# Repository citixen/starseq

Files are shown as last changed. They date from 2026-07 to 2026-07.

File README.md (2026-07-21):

# starseq — project overview

This project and all files in it represent the state of the project as it was during EMF Camp 2026, where it ran as an installation (in the baking sun) for 4 days. It largely worked without incident for that time and the concept and implementation are at least a bit proven. However, the project is offered as-is and without any ability to support it further if you decide to try building one for yourself. It all works in my build, but that doesn't mean it will for you. I may have forgotten critical setup components, and I may have done something weird and forgotten to document it. Sorry if I did. I've also not really documented any of the specifics of how I wired it together in my build. It was horrible spaghetti (see pics) and you can definitely do better just using the pin allocations in the code to guide you. Best of luck! Use this as a jumping off point to something bigger and better! I know I will!

---

## what starseq is

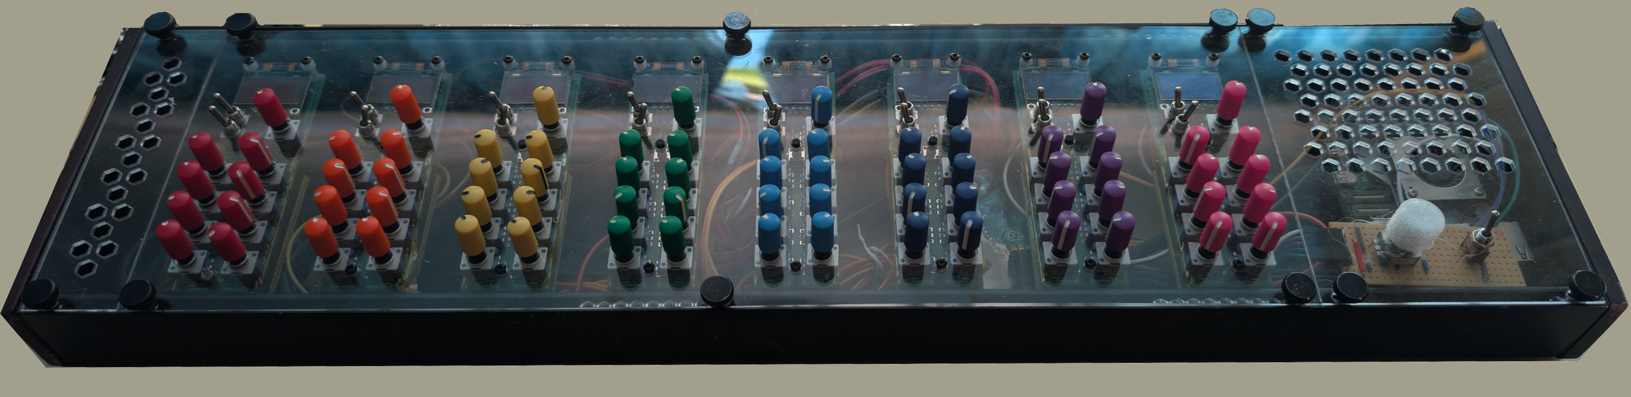
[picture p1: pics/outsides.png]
Image of the control interface for an 8-track sequencer, with a large number of coloured potentiometers and a perspex panel behind which can be seen a raspberry pi


**starseq** is an 8-track MIDI step sequencer whose musical content is generated from the real-time positions of naked-eye-visible stars in the sky above the instrument's physical location. Each of the 8 tracks claims a wedge ("slice") of the compass — a band of azimuth and a brightness threshold — and turns whichever stars currently sit inside that wedge into a step sequence: azimuth decides *when* (which step) a note falls, altitude decides *what pitch*, and brightness/colour decide *how loud* and *how long*. Because the sky moves, the sequences drift and evolve on their own, in real astronomical time or sped up/slowed/reversed via a simulated clock. Planets and constellation lines are drawn for visual context only currently — but the data is there for future uses.

The instrument is physically and electronically a three-tier system:

```
┌──────────────────────┐      ┌──────────────────────┐     ┌─────────────────────┐
│ 8 × Instrument       │      │ Controller Interface │     │ Sequencer           │
│ Controllers          │────▶│  (aggregator)        │────▶│ (Raspberry Pi 5)    │
│ (one per track)      │ UART │ RP2040 Pico          │ UART│ Sky engine, MIDI,   │
│ 9 pots + 2 switches  │      │                      │     │ display, output     │
│ + button + OLED      │      │                      │     │                     │
└──────────────────────┘      └──────────────────────┘     └─────────────────────┘
     ESP32-S3 DevKit             8-port aggregator            pygame + skyfield
     per track                  → single uplink               + MIDI + GPIO
```

A performer turns physical pots on 8 identical hand controllers; those settings flow up through an aggregating interface board to a Raspberry Pi, which combines them with live sky data to produce and play an 8-track MIDI sequence, rendered simultaneously as a star-dome visualisation.

The instrument is housed in a standard cheap 104hp eurorack case, with some cheap bulkhead pass-thrus to get USB and HDMI from the Pi outside the case, and to get power in.

---

## tier 1 — instrument controller (one per track, ×8)

**Hardware:** ESP32-S3 DevKit C-1 (cheap - and has 2 x 12-bit SAR ADCs). Per unit: 9 potentiometers, 2 SPDT switches (Mute/Stop; Mono/Poly), 1 momentary push-button (play direction), a 128×64 SSD1306 2 colour (yellow/blue) OLED over I2C (mounted inverted, yellow  strip at the bottom), and a UART link out to the Controller Interface. The PCB files are included for the version used at EMF 26. These were made quickly and down to a price. Better board layouts and control configurations can be achieved!

**Role:** turn physical control positions into a per-track parameter packet and keep the OLED showing current state.

In the published firmware, all 9 pots are live simultaneously on a single page (an earlier multi-page design was collapsed to one page for simplicity). Each pot drives one parameter directly: length, base note, note range, slice centre, step divider, slice width, play mode, slice brightness, and duration max (which rescales live across `1…current length`). The two switches and the button cover mute/stop, mono/poly, and play-direction toggle. Parameters that are sent from the controller but which no longer have a dedicated pot in this  revision — velocity lo/hi, duration lo, parameter mode, MIDI channel — are  held at fixed firmware defaults but are still transmitted in full on every  packet, because **the wire format was deliberately left unchanged** from an  earlier, fuller-featured revision. This means the interface and sequencer  require no changes to accept this simplified controller, and a future firmware  revision could re-expose those parameters on interface pages without touching  downstream code.

The controller debounces inputs, applies deadbanding to pot readings to try  to avoid flooding the serial link with jitter, and transmits change-driven updates plus a periodic heartbeat. It persists its working state to the ESP32's flash-backed NVS (a packed, versioned, CRC-checked 22-byte struct), so a power cycle resumes the previous session instead of resetting to defaults — with **pick-up logic** at boot only: a restored pot value is shown with a directional arrow on the OLED until the performer physically turns that pot through the stored value, at which point it goes live.

---

## tier 2 — controller interface (aggregator)

**Hardware:** a single Raspberry Pi Pico (RP2040), with 8 independent PIO-UART port pairs (one RX/TX pair per controller) plus one hardware UART uplink to the Raspberry Pi. All built onto a small vero board, along with power distribution for the controllers. Takes in a single USB-C connection for 5V.

**Role:** a hardware-agnostic multiplexer. It runs 8 concurrent per-port receivers, validates and decodes each controller's packet (frame boundaries, protocol version, CRC, field ranges), maintains a live state table (one record per controller, with sequence number, last-RX timestamp, and a waiting/online/stale/offline status derived from timeout), and republishes that aggregated state upstream to the Pi as a single serial stream. A single-port fault never blocks the other 7 ports.

Two upstream message shapes exist: periodic **full snapshots** (all 8 controller records in one packet, sent roughly every 400 ms) and **delta packets** (a single controller's record, sent immediately whenever a field changes beyond a small deadband). This keeps the uplink responsive to live pot movement without needing to stream continuously.

---

## tier 3 — sequencer (Raspberry Pi 5)

**Hardware:** a Raspberry Pi 5, with a serial connection to the interface board, a 20 pulse rotary encoder and an SPDT connected to GPIO pins. Outputs HDMI, and has USB connections - all passed through the case.

**Role:** the brain of the instrument. Runs headlessly, receives the  aggregated controller state over serial, computes the live sky, turns  sky + per-track parameters into MIDI, and renders everything to an HDMI/DSI display via pygame.

### architecture

The application is a set of daemon background threads (Serial RX, Input Handler, Sky Engine, Sequence Builder, Sequencer Engine, MIDI Clock Input, GPS Receiver) plus one blocking main-thread loop for the pygame display — pygame's video backend must own the main thread on Linux/the Pi. Shared state moves through thread-safe primitives only: per-track locks, bounded queues, and a lock-free double-buffered (plus one "pending") sequence store per track. The sequencer engine requests real-time (`SCHED_FIFO`) scheduling and is never allowed to block on sky computation, serial I/O, GPS parsing, or rendering.

### midi generation

1. **Sky Engine** recomputes, on a fixed ~250 ms interval, the alt/az of    every star in the Yale Bright Star Catalogue (via Skyfield/DE421) and of     7 planets, using a **simulated clock** that can run at real speed, be     frozen, fast-forwarded, or reversed (a discrete multiplier ladder from     ‑64× to 64×), or jumped to an explicit date via a preset events picker     or manual date fields. Only stars above the horizon and brighter than     magnitude 6.5 (naked-eye) survive into the published snapshot; planets     are published on a separate, sequencing-blind channel.
2. **Sequence Builder** takes each track's slice (`slice_centre` ±    `slice_width/2`, wrap-around handled mod 360) and `slice_brightness`    (mapped to a magnitude cutoff), filters the star snapshot down to that    track's candidate stars, buckets them into steps by azimuth, assigns each    a MIDI note from altitude (mapped onto the valid in-scale notes within    `base_note … base_note + note_range`), and picks which candidate(s) in a    step actually sound according to the track's **play mode** (random,    highest, lowest, middle, first, last, brightest, dimmest) and mono/poly    mode. Velocity comes from magnitude and duration from B‑V colour index    (or from static/per-loop-randomised values, depending on `param_mode`).    Loop-randomised tracks stage their next sequence in a third "pending"    buffer so a re-roll never disturbs a note already playing mid-loop; the    swap happens only at that track's own loop boundary.
3. **Sequencer Engine** is the real-time clock: internal PPQN-24 tick    generation or external MIDI clock, per-track step/tick accumulators so    tracks can run at independent step-dividers while staying phase-locked,    forward/reverse play direction, note-on/note-off scheduling, and MIDI    output. It also drives the flash events consumed by the display so that    firing notes visibly pulse on the star dome and sequencer grid in the    same colour as the track that's playing them.
4. **MIDI channel routing** is decoupled from whatever channel a controller    itself reports: a transport-bar **CH MODE** setting chooses between the    controller-launch default, sequential per-track channels, all-tracks-on-    one-channel, or trusting the controller's own reported channel.

### display

A pygame UI running at 30 fps shows a polar-projected star dome (stars, planet hexagon markers, constellation lines), an 8-row sequencer grid, and an always-visible transport bar (no modal menu — a single focus pointer moves around a flat ring of stops for location, view/brightness toggles, tempo, clock source, key/scale, polyphony limit, MIDI device, channel mode, and simulated time). Layout adapts automatically to portrait, landscape, or extreme-aspect screens, and three independent brightness toggles plus a 10-mode **VIEW** setting control how much of the sky, wedges, and note flashes are visible without ever touching what's actually being sequenced.

### inputs

A rotary encoder + SPDT play/stop switch (GPIO on the Pi) provide local transport control, with a keyboard fallback for headless/dev use. Location can come from config defaults, manual entry, a USB NMEA GPS receiver, or a built-in list of preset cities — switchable live, without a restart.

---

## end-to-end data flow

```
Pot/switch/button position (Instrument Controller)
   → smoothed, deadbanded, mapped to parameter range
   → packed into a 21-byte controller record, COBS-framed, CRC-8
   → UART to Controller Interface

Controller Interface
   → validated per-port, staged into a per-controller state table
   → status (waiting/online/stale/offline) derived from packet recency
   → re-aggregated into full (8-record) or delta (1-record) packets
   → COBS-framed, CRC-8, UART uplink to Raspberry Pi

Raspberry Pi — Serial RX thread
   → CRC-checked, decoded, written directly into that track's TrackState
     under its lock; sequence_dirty = True

Sky Engine (independent of the above)
   → simulated time → star & planet alt/az → filtered snapshot published

Sequence Builder
   → combines the track's parameters with the star snapshot
   → produces a step sequence (notes, velocities, durations)

Sequencer Engine
   → ticks, advances steps, fires MIDI Note On/Off, schedules flash events

MIDI Output + Display
   → notes/clock out over MIDI; star dome & grid rendered in sync
```

A single 21-byte controller record schema is shared verbatim across all three tiers — the Instrument Controller populates it, the Controller Interface forwards it unmodified, and the Sequencer is the only tier that interprets it semantically (resolving the step-divider index to an actual ratio, applying channel-mode overrides, etc.).

---

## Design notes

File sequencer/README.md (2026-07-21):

# starseq

An 8-track MIDI step sequencer whose musical sequences are derived from the real-time positions of naked-eye-visible stars in the sky above the instrument's location. Runs headlessly on a Raspberry Pi 5 with a pygame UI on an attached HDMI or DSI display.

---

## Hardware requirements

| Component | Notes |
|---|---|
| Raspberry Pi 5 | Tested target; Pi 4 may work with reduced sky recalculation rate |
| HDMI or DSI display | Any resolution ≥ 800 × 480 |
| MIDI interface | USB class-compliant or GPIO UART MIDI out |
| Controller interface | Connected to UART0 (BCM 14/15) at 57600 8N1 |
| Rotary encoder | CLK → BCM 17, DT → BCM 18, SW → BCM 27 (pull-ups applied in software) |
| SPDT play/stop switch | → BCM 16 (pull-up applied in software) |

All hardware inputs are optional at runtime — see [Command-line arguments](#command-line-arguments).

---

## OS requirements

**Raspberry Pi OS Bookworm Lite** (headless, no desktop environment). A desktop environment is not required or expected. The display is driven directly via KMS/DRM.

---

## Software installation

### 1. Clone the repo to the Pi

```bash
git clone <repo-url> ~/starseq
cd ~/starseq
```

Or copy files over SSH:

```bash
scp -r ./starseq pi@<pi-address>:~/starseq
```

### 2. Install system SDL2 development packages

pygame must be compiled against the system SDL2 to gain KMS/DRM display support. Install the development headers first:

```bash
sudo apt update
sudo apt install --no-install-recommends \
    libsdl2-dev libsdl2-image-dev libsdl2-ttf-dev \
    libsdl2-mixer-dev python3-dev
```

### 3. Create and activate a Python virtual environment

```bash
cd ~/starseq
python3 -m venv .venv
source .venv/bin/activate
```

### 4. Install Python dependencies

```bash
pip install -r requirements.txt
```

### 5. Install pygame from source

The pre-built pygame wheel from PyPI bundles its own SDL2 which does not include the KMS/DRM driver required for Bookworm Lite. Compiling from source links against the system SDL2 instead:

```bash
pip install --force-reinstall --no-binary pygame pygame
```

This takes several minutes on the Pi. Verify the correct SDL version afterwards:

```bash
python -c "import pygame; print(pygame.get_sdl_version())"
# Should print (2, 26, x) — the system SDL2 version, not (2, 28, x)
```

### 6. Add the user to the display device groups

KMS/DRM access requires membership of the `video` and `render` groups:

```bash
sudo usermod -a -G video,render $USER
```

Log out and back in for the group change to take effect.

### 7. Verify the data files are present

```
data/de421.bsp      ← JPL ephemeris (~17 MB, included)
data/bsc5.json      ← Yale Bright Star Catalog (included)
```

If `de421.bsp` is missing, skyfield can download it on first run (requires internet access). Place the downloaded file in the `data/` directory.

---

## Configuration

All tuneable constants live in [`config.py`](config.py). Edit them directly before deploying.

### Geographic location

```python
LOCATION_LAT  = 51.75    # decimal degrees (positive = North)
LOCATION_LON  = -0.22    # decimal degrees (positive = East)
LOCATION_ELEV = 80       # metres above sea level
```

### Serial port

By default the serial RX thread opens `/dev/ttyAMA0` (UART0 on the Pi). Override at runtime:

```bash
SERIAL_PORT=/dev/ttyS0 python main.py
```

Or change the default in `config.py`:

```python
SERIAL_PORT = "/dev/ttyAMA0"
```

### Display options

```python
SHOW_OUT_OF_SCOPE_STARS = True    # False hides stars not in any slice
SHOW_MIDI_NOTE_LABELS   = False   # True shows sounding note names in the grid
TARGET_FPS              = 30
```

### Sequencer defaults

```python
MAX_POLY_NOTES         = 5        # maximum simultaneous notes per track in poly mode
PPQN                   = 24       # MIDI clock resolution (standard)
SKY_RECALC_INTERVAL_MS = 250      # minimum ms between sky recomputations
```

---

## Enabling UART0 on the Pi

The Pi's primary UART must be freed from the Bluetooth controller and enabled for general use.

Add to `/boot/firmware/config.txt`:

```
dtoverlay=disable-bt
enable_uart=1
```

Disable the serial console:

```bash
sudo raspi-config
# → Interface Options → Serial Port
# "Would you like a login shell accessible over serial?" → No
# "Would you like the serial port hardware to be enabled?" → Yes
```

Reboot.

---

## Running

### Command-line arguments

```
python main.py [--no-gpio] [--no-serial] [--resolution WxH]
```

| Argument | Effect |
|---|---|
| `--no-gpio` | Skip the GPIO input handler. Use keyboard shortcuts instead (see [Controls](#controls)). |
| `--no-serial` | Skip the serial RX thread. All 8 tracks are initialised with built-in defaults so the sequencer produces sound without a controller attached. |
| `--resolution WxH` | Force a specific window size, e.g. `800x480` or `1920x1080`. Useful for testing layouts at different screen sizes. |

These flags are independent and can be combined:

```bash
# Full hardware
python main.py

# Pi with display + MIDI, no controller attached yet
python main.py --no-serial

# Development on a desktop machine (no GPIO, no serial)
python main.py --no-gpio --no-serial
```

### SDL video driver (automatic)

The display renderer auto-detects the SDL video driver at startup. No environment variables need to be set manually:

| Environment | Driver selected |
|---|---|
| Wayland session (`WAYLAND_DISPLAY` set) | `wayland` |
| X11 session (`DISPLAY` set) | `x11` |
| Bookworm Lite / no display server | `kmsdrm` (requires `video`/`render` group membership) |

The selected driver is logged at startup. Override by setting `SDL_VIDEODRIVER` before launching if needed.

### Foreground (development / testing)

```bash
cd ~/starseq
source .venv/bin/activate
python main.py --no-gpio --no-serial
```

### Autostart on boot (systemd)

Create `/etc/systemd/system/starseq.service`:

```ini
[Unit]
Description=starseq
After=network.target sound.target

[Service]
User=<user>
WorkingDirectory=/home/<user>/starseq
ExecStart=/home/<user>/starseq/.venv/bin/python main.py
Restart=on-failure
RestartSec=5
SupplementaryGroups=video render audio
StandardOutput=journal
StandardError=journal

[Install]
WantedBy=multi-user.target
```

No `DISPLAY` or `SDL_VIDEODRIVER` environment variables are needed — the application detects the correct driver automatically. If the Pi boots to a desktop session, set `Environment=SDL_VIDEODRIVER=wayland` (or `x11`) explicitly to skip the auto-detection.

Enable and start:

```bash
sudo systemctl daemon-reload
sudo systemctl enable starseq
sudo systemctl start starseq
```

View logs:

```bash
journalctl -u starseq -f
```

---

## Real-time scheduling (recommended)

The sequencer engine thread requests `SCHED_FIFO` priority automatically. Grant the permission without running as root:

```bash
sudo nano /etc/security/limits.d/starseq.conf
```

```
<user>  -  rtprio  99
<user>  -  memlock  unlimited
```

Log out and back in (or reboot) for this to take effect.

---

## Controls

### Physical (Raspberry Pi hardware)

| Control | Action |
|---|---|
| SPDT switch | Toggle global play / stop |
| Rotary encoder — turn | Adjust the focused parameter (BPM by default) |
| Encoder button — short press | Advance focus to the next parameter in the transport bar |
| Encoder button — hold ≥ 2 s | Reset simulated sky clock to current UTC (multiplier unchanged) |

### Keyboard (always available in the pygame window)

| Key | Action |
|---|---|
| `P` | Toggle play / stop |
| `R` | Reset simulated sky clock to current UTC |
| `Space` / `Enter` | Advance focus to the next parameter in the transport bar |
| `↑` / `↓` | Navigate parameters without changing value |
| `→` / `+` / `=` | Increase focused parameter value |
| `←` / `-` | Decrease focused parameter value |
| `Escape` | Quit |

### Parameter bar

The transport bar across the top of the window is the parameter menu — it is always visible. All global parameters are shown as labelled columns; the focused column is highlighted.

| Parameter | Range / options |
|---|---|
| Location menu | menu for location settings |
| Constalations | switch on/off |
| Planets | switch on/off |
| BPM | 20.0 – 300.0 (step 1) |
| Clock Source | internal / external |
| Key | C, C#, D … B |
| Scale | Major, Minor, Dorian, Phrygian, Lydian, Mixolydian, Locrian, Whole Tone, Pentatonic Maj, Pentatonic Min, Chromatic |
| Max Poly | 1 – 8 notes per step |
| MIDI Device | cycles through connected output ports |
| MIDI Channel mode | default, sequential, all 1 channel, self-report |
| Time Multiplier | x1, x2, x4, x8 … x64, FROZEN, and negative mirror values |
| Clock menu | menu for clock settings |
| Layout | switch between showing tracks, dimming tracks, and hiding tracks |

Changing **Key**, **Scale**, or **Max Poly** immediately triggers a sequence rebuild on all tracks. Changing **MIDI Device** reopens the MIDI output port.

---

## Display layout

```
┌─────────────────────────────────────────────────────────────────────────────────────────────────────────────────────────────┐
│ LOC | CONST | PLNT | VIEW | PULSE | 120.0 BPM |  INT | C |  MAJ | POLY 5 | USB MIDI | MIDI CH MODE | x1 | CLK | LAYOUT | ▶ │  ← transport bar
├──────────────────────────────────────────────────────────────┬──────────────────────────────────────────────────────────────┤
│                                                              │  track 1 ████████████████░░░░░░░░░░░░░░░░  ▶                │
│              star dome                                       │  track 2 ████████████░░░░░░░░░░░░░░░░░░░░  ▶                │
│             (polar plot,                                     │  track 3 ░░░░░░░░░░░░░░░░░░░░░░░░░░░░░░░░  ■                 │
│               N at top)                                      │  ...                                                         │
│                                                              │  track 8 ████████████████████████████████  ▶                │
└──────────────────────────────────────────────────────────────┴──────────────────────────────────────────────────────────────┘
```

- **Star dome**: circular polar projection; centre = zenith, edge = horizon, north at top. Track slice wedges are outlined in their track colour. Stars are coloured by which track's slice they fall in. Stars pulse briefly when a note fires from them.
- **Sequencer grid**: 8 rows (one per track); each row divided into `length` step cells. The active step is highlighted. Small dots within each cell show the notes available at that step, positioned vertically by MIDI pitch. Stale or offline controller rows are hatched.
- **Transport bar**: always-on strip showing Location menu, constellaion and planet switches, BPM, clock source, key, scale, max poly, MIDI device, time multiplier, clock controls, and play/stop icon.

---

## Simulated time multiplier

The sky engine runs on a simulated clock that can be accelerated, frozen, or reversed relative to wall-clock time. Set it via the **Time Multiplier** entry in the parameter menu.

| Multiplier | Effect |
|---|---|
| `x1` | Real time — sky matches actual UTC |
| `> x1` | Fast-forward — stars sweep faster |
| `FROZEN` | Sky locked at current simulated moment |
| Negative | Stars move backward |

Changing the multiplier only changes the rate of advance. Not the time. The **long-hold gesture** (≥ 2 s on the encoder button, or `R` on keyboard) snaps the simulated clock back to current UTC (as best as the Pi knows. With no NTP it resets to whatever the last "known" time was) without altering the multiplier.

If the simulated time drifts outside the bounds of the ephemeris data (approximately 1900–2050 for DE421), the clock is automatically reset to current UTC.

---

## Development and testing on other systems

```bash
# Windows (PowerShell)
.venv\Scripts\activate
python main.py --no-gpio --no-serial --resolution 1280x720

# macOS / Linux
source .venv/bin/activate
python main.py --no-gpio --no-serial --resolution 1280x720
```

- `--no-gpio` suppresses the `gpiozero/lgpio not available` warning and skips the idle input handler thread.
- `--no-serial` prevents errors from a missing serial port and starts all tracks in playable mono mode immediately.
- `--resolution` is recommended on desktop to get a windowed (non-fullscreen) display.
- MIDI output works via any rtmidi backend (Windows MIDI Mapper, CoreMIDI, ALSA).

---

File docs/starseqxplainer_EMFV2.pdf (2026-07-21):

# starseq - music from the stars

An 8-track sequencer that reads its notes from the sky.

The sky is the score

Each of the 8 tracks watches a slice of sky - an arc of azimuth with a centre and a width. Only stars inside a track's slice, and bright enough to pass its threshold, can sound on that track. As the sky turns, the sequence rebuilds.

A slice splits into as many step-wedges as the track's length. When several stars share a step, play mode picks which sound (random, highest/lowest, brightest/dimmest…). Mono keeps one; poly keeps many.

Anywhere, any when, any speed

The device knows where it is using GPS, and uses that to calculate the visible stars. You can manually set this to any lat/lon - or pick from a list of presets - and automatically travel to that location!

The sky runs on a simulated clock. The time multiplier can speed it up, freeze it, or reverse it, without ever jumping. A long-press on the encoder snaps it back to the real moment. Or you can set the time to a significant event and experience what the stars sounded like then.

Instant space and time travel at the turn of a dial!

The skydome

Represents a polar plot of the sky: zenith at centre, horizon at the edge, north at top. Stars pulse on a note-on. Planets are hexagon markers - and are visual only, not sequenced.
View modes sets how brightly this is all drawn.

Star properties → musical parameters

STAR | TRACK/STEP/NOTE
Altitude height above horizon | Pitch, within scale & note range
Azimuth angle from slice center | Step position

B−V colour
index
blue → red

Note duration

Magnitude
apparent
brightness

Velocity, and the slice
brightness gate

Musical - or not

The user can apply tempo, scale and key constraints, with which to constrain the generation of musical notes and steps. Or chromatic mode can be applied for some chaos!

Tempo can be set externally, or can be sent out from the sequencer to other midi devices.

# starseq - controller

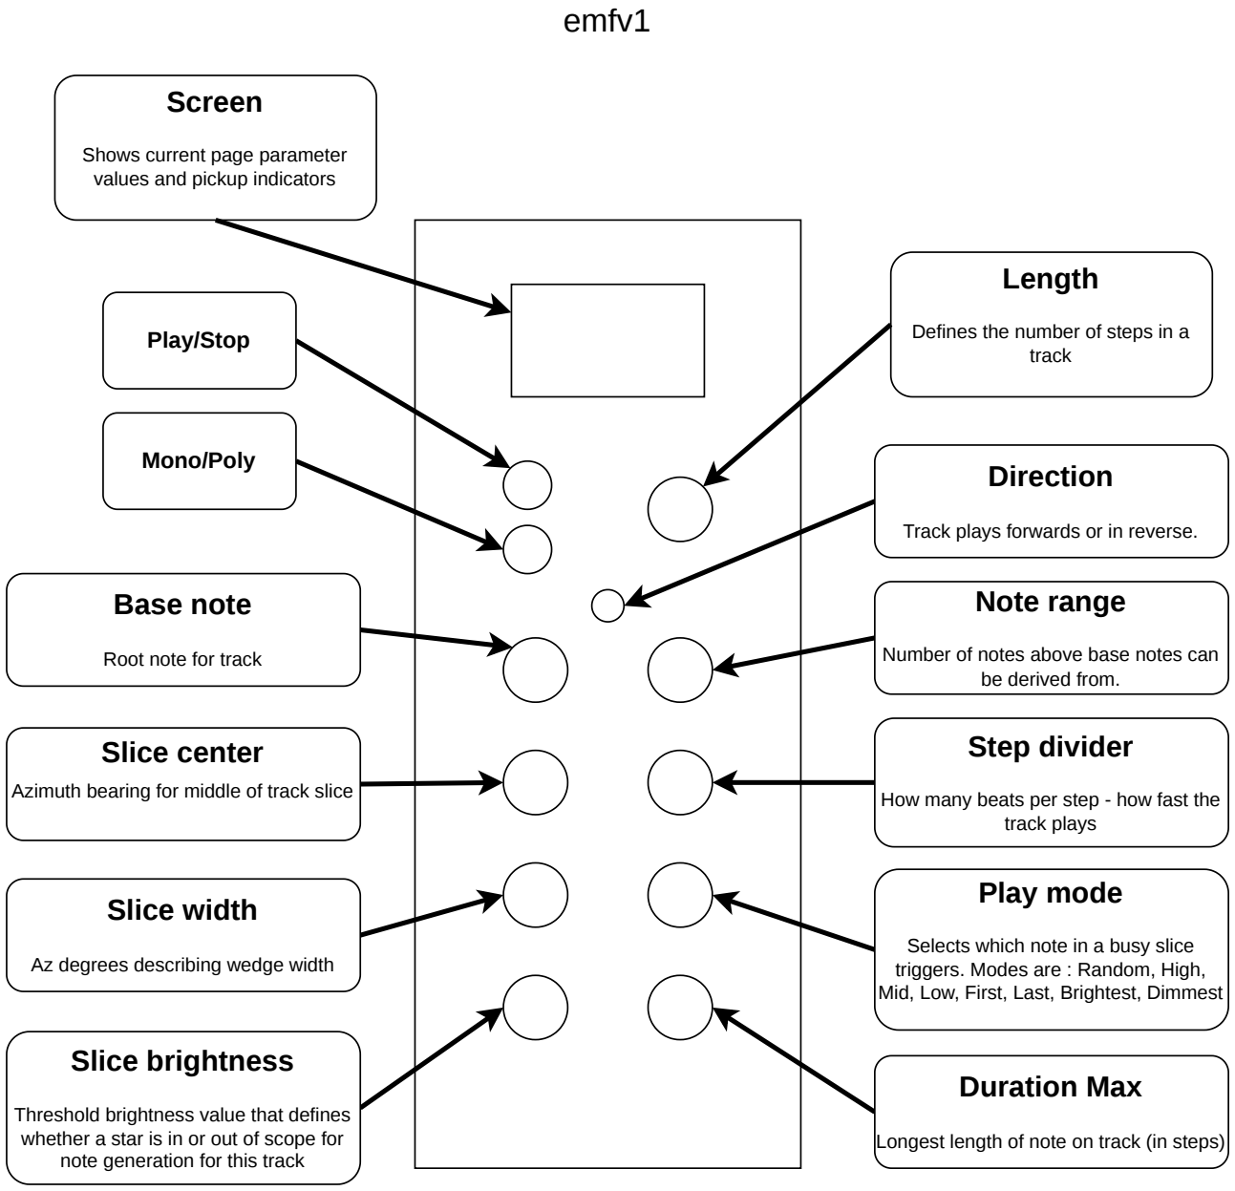
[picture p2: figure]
Screen; Shows current page parameter values and pickup indicators; Length; Defines the number of steps in a track; Play/Stop; Mono/Poly; emfv1; Duration Max; Direction; Track plays forwards or in reverse.; Base note; Root note for track; Play mode; Selects which note in a busy slice triggers. Modes are : Random, High,; Step divider; How many beats per step - how fast the track plays; Note range; Number of notes above base notes can be derived from.; Slice center; Slice width; Az degrees describing wedge width; Slice brightness; Threshold brightness value that defines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

Longest length of note on track (in steps)

Mid, Low, First, Last, Brightest, Dimmest

Azimuth bearing for middle of track slice

whether a star is in or out of scope for

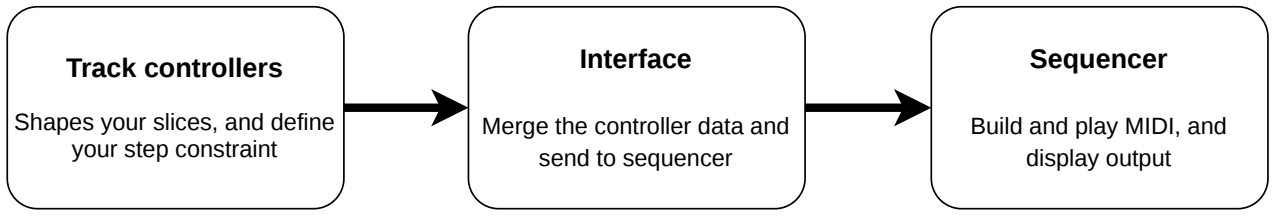
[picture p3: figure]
Track controllers; Shapes your slices, and define your step constraint; Interface; Merge the controller data and send to sequencer; Sequencer; Build and play MIDI, and display output

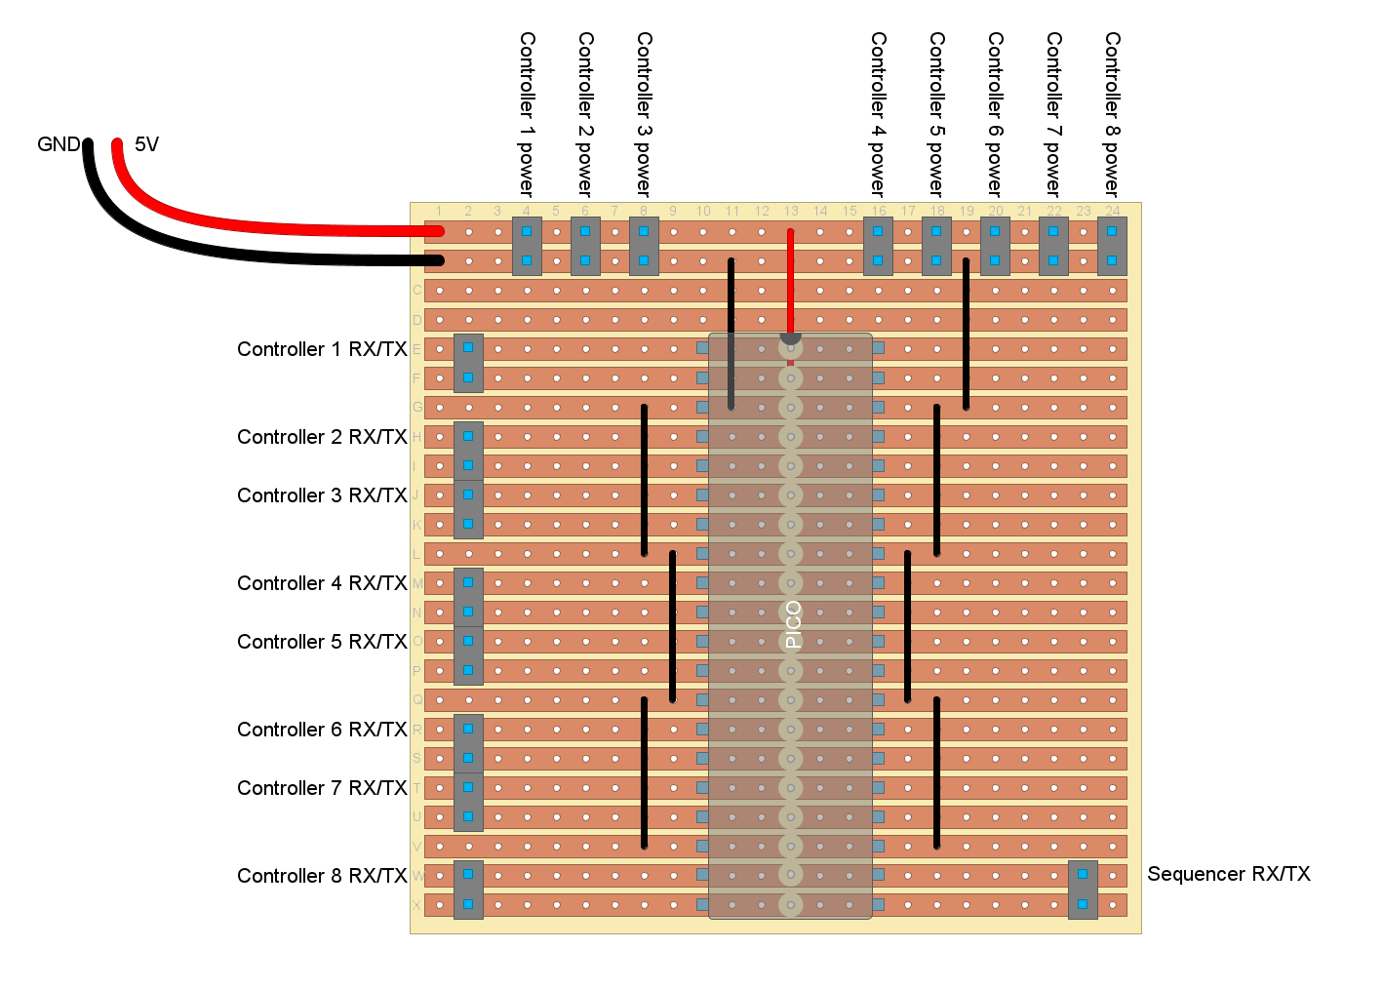
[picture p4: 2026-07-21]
hardware/interface/interface vero layout.png

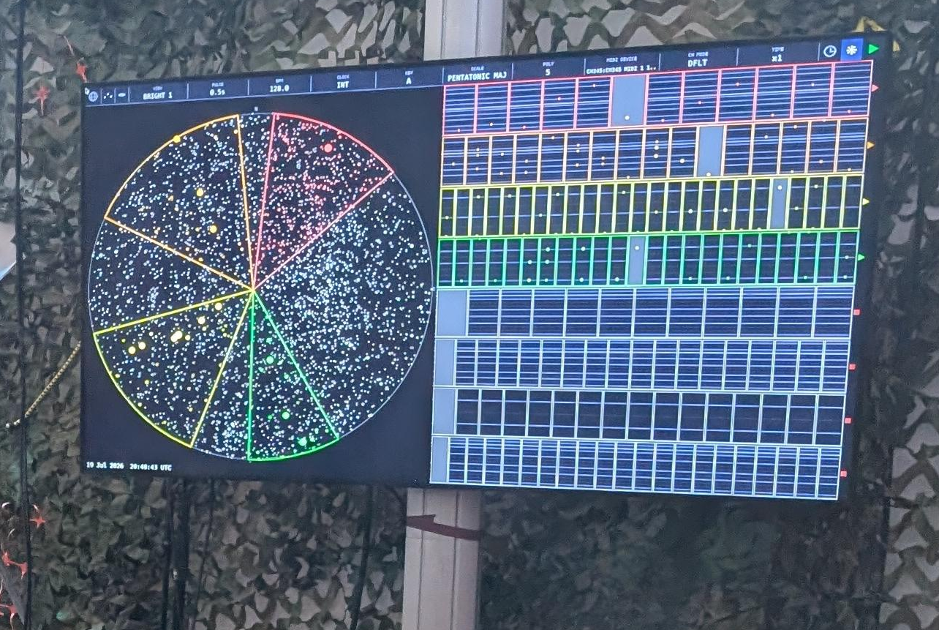
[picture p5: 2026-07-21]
pics/interfaceinaction.png

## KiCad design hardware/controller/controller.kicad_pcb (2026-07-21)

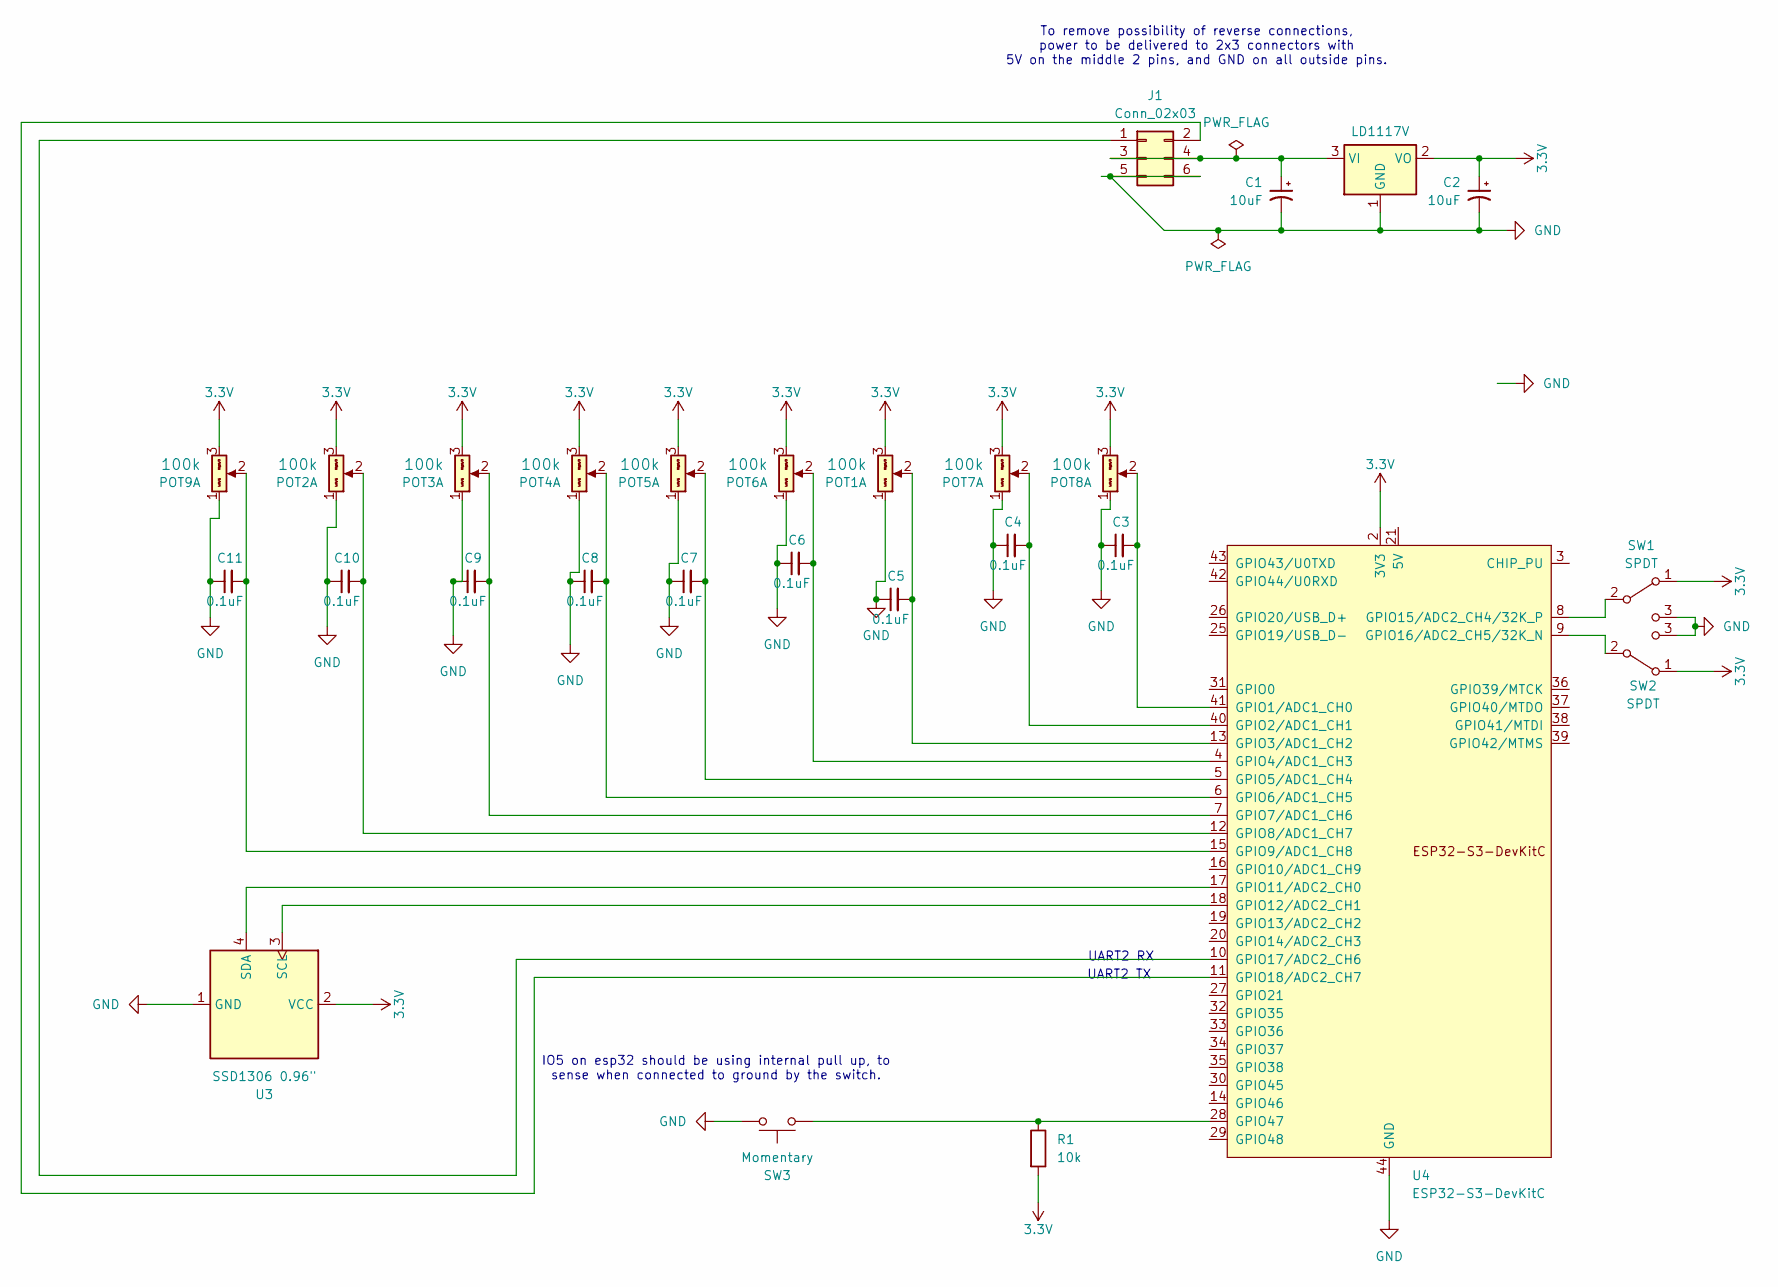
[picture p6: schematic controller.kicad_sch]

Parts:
C1, C2: 10uF; CP_Radial_D5.0mm_P2.50mm; Part Number EEE-FN1A100R; JLCPCB ID C176661
C3, C4, C5, C6, C7, C8, C9, C10, C11: 0.1uF; C_0805_2012Metric_Pad1.18x1.45mm_HandSolder; Voltage 25V; Tolerance 20%
J1: Conn_02x03; PinHeader_2x03_P2.54mm_Vertical
POT1, POT2, POT3, POT4, POT5, POT6, POT7, POT8, POT9: 9mm_NoDet_100k_Knurled_Lined; Pot_9mm_regularstylewiderleg; Part Number RV16AF-4A-15FW-B100K-3
R1: R_Generic; R_Axial_DIN0207_L6.3mm_D2.5mm_P10.16mm_Horizontal
SW1, SW2: SPDT; Switch_Toggle_SPDT_SubMini
SW3: Momentary; SW_PUSH_6mm
U2: LD1117V; TO-220-3_Horizontal_TabDown
U3: SSD1306 0.96"; 128x64OLED 0.96
U4: ESP32-S3-DevKitC; ESP32-S3-DevKitC-WIDER

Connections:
3.3V: C2.1, POT1.3 (Right), POT2.3 (Right), POT3.3 (Right), POT4.3 (Right), POT5.3 (Right), POT6.3 (Right), POT7.3 (Right), POT8.3 (Right), POT9.3 (Right), R1.2, SW1.1 (A), SW2.1 (A), U2.2 (VO), U3.2 (VCC), U4.1 (3V3), U4.2 (3V3)
GND: C1.2, C2.2, C3.1, C4.1, C5.1, C6.1, C7.1, C8.1, C9.1, C10.1, C11.1, J1.5, J1.6, POT1.1 (Left), POT2.1 (Left), POT3.1 (Left), POT4.1 (Left), POT5.1 (Left), POT6.1 (Left), POT7.1 (Left), POT8.1 (Left), POT9.1 (Left), SW1.3 (C), SW2.3 (C), SW3.2, U2.1 (GND), U3.1 (GND), U4.22 (GND), U4.23 (GND), U4.24 (GND), U4.44 (GND)
unnamed: C5.2, POT1.2 (Center), U4.13 (GPIO3/ADC1_CH2)
unnamed: C10.2, POT2.2 (Center), U4.12 (GPIO8/ADC1_CH7)
unnamed: C9.2, POT3.2 (Center), U4.7 (GPIO7/ADC1_CH6)
unnamed: C8.2, POT4.2 (Center), U4.6 (GPIO6/ADC1_CH5)
unnamed: C7.2, POT5.2 (Center), U4.5 (GPIO5/ADC1_CH4)
unnamed: C6.2, POT6.2 (Center), U4.4 (GPIO4/ADC1_CH3)
unnamed: C4.2, POT7.2 (Center), U4.40 (GPIO2/ADC1_CH1)
unnamed: C3.2, POT8.2 (Center), U4.41 (GPIO1/ADC1_CH0)
unnamed: C11.2, POT9.2 (Center), U4.15 (GPIO9/ADC1_CH8)
unnamed: SW1.2 (B), U4.8 (GPIO15/ADC2_CH4/32K_P)
unnamed: SW2.2 (B), U4.9 (GPIO16/ADC2_CH5/32K_N)
unnamed: C1.1, J1.3, J1.4, U2.3 (VI)
unnamed: U3.3 (SCL), U4.18 (GPIO12/ADC2_CH1)
unnamed: U3.4 (SDA), U4.17 (GPIO11/ADC2_CH0)
unnamed: J1.1, U4.10 (GPIO17/ADC2_CH6)
unnamed: J1.2, U4.11 (GPIO18/ADC2_CH7)
unnamed: R1.1, SW3.1, U4.28 (GPIO47)

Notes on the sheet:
UART2 RX
To remove possibility of reverse connections, power to be delivered to 2x3 connectors with 5V on the middle 2 pins, and GND on all outside pins.
UART2 TX
IO5 on esp32 should be using internal pull up, to sense when connected to ground by the switch.

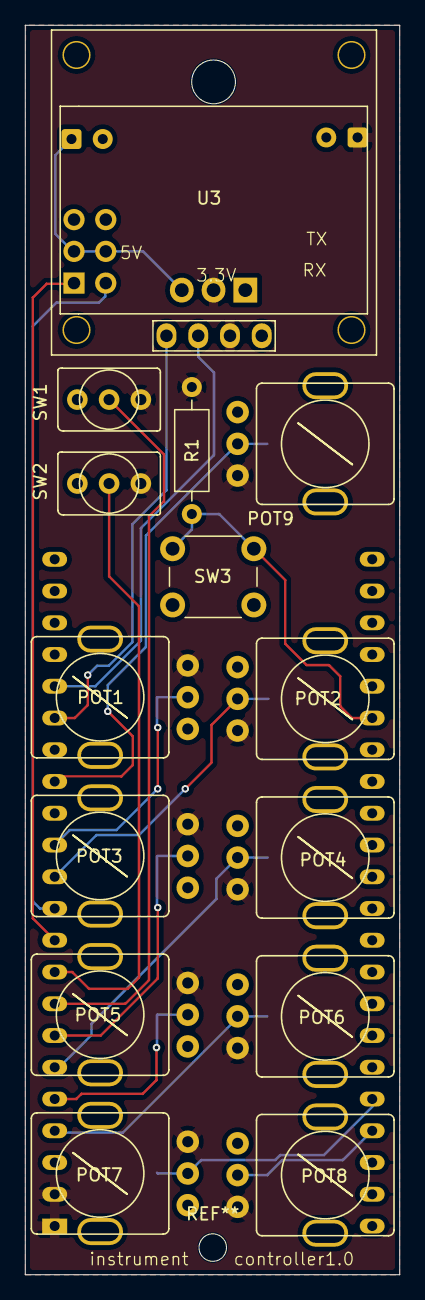
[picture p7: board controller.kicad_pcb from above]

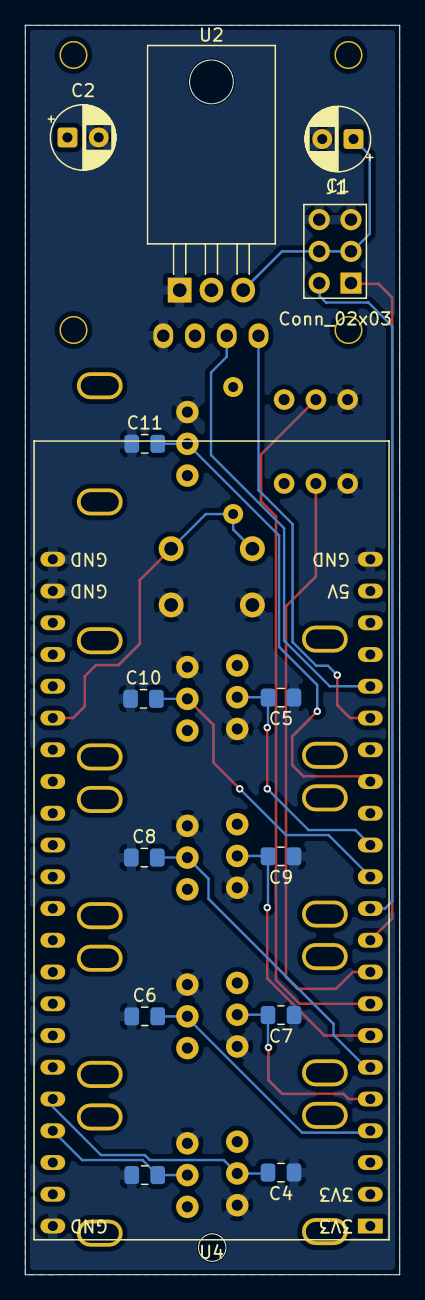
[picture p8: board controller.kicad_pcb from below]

Board: 2 copper layers, 30.0 x 99.9 mm, 28 parts (14 on the bottom side), 19 nets.

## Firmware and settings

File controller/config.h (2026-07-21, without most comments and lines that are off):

#pragma once
#define CONTROLLER_ID   8       // Set to 1–8 per physical unit
#define PIN_POT1     9      // Length          — GPIO3  (also U0RXD; fine after boot)
#define PIN_POT2     3      // Base note        — GPIO8
#define PIN_POT3     8      // Note range       — GPIO7
#define PIN_POT4     7      // Slice centre     — GPIO6
#define PIN_POT5     6      // Step divider     — GPIO5
#define PIN_POT6     5      // Slice width      — GPIO4
#define PIN_POT7     4      // Play mode        — GPIO1
#define PIN_POT8     2      // Slice brightness — GPIO2
#define PIN_POT9     1      // Duration Hi      — GPIO9
#define PIN_SPDT1   15      // Mute/Stop switch     — GPIO15 (active HIGH)
#define PIN_SPDT2   16      // Mono/Poly switch     — GPIO16
#define PIN_BTN_DIR 47      // Direction toggle button — GPIO47
#define PIN_I2C_SDA  11     // SDA — GPIO11
#define PIN_I2C_SCL  12     // SCL — GPIO12
#define OLED_WIDTH      128
#define OLED_HEIGHT      64
#define OLED_RESET_PIN   -1     // No dedicated reset pin; share system reset
#define OLED_I2C_ADDR  0x3C     // Most common SSD1306 address; try 0x3D if not found
#define PICKUP_TOLERANCE            2   // mapped-value units (general)
#define PICKUP_TOLERANCE_PLAY_MODE  1   // play mode index (0–7, tight range)
#define PICKUP_TOLERANCE_STEP_DIV   1   // step divider index (0–12)
#define PICKUP_TOLERANCE_SLICE_CTR  4   // slice centre degrees (0–359)
#define PICKUP_TOLERANCE_SLICE_WID  4   // slice width degrees (1–360)
#define PICKUP_TOLERANCE_SLICE_BRI  3   // slice brightness (0–100)
#define PICKUP_TOLERANCE_DUR        2   // duration hi (steps, range 1..len)
#define PICKUP_CONFIRM_CYCLES       4   // consecutive scans within tolerance
#define PIN_SERIAL_RX   17      // GPIO17 — RX from interface (future use)
#define PIN_SERIAL_TX   18      // GPIO18 — TX to interface
#define SERIAL_BAUD     57600
#define HEARTBEAT_MS    500
#define TX_DEADBAND_BASE_NOTE   1
#define TX_DEADBAND_NOTE_RANGE  1
#define TX_DEADBAND_VEL         1
#define TX_DEADBAND_DUR         1
#define PROTO_VERSION   5
#define NVS_NAMESPACE       "ctrl_state"  // Preferences namespace
#define NVS_BLOB_KEY        "rec"         // single blob key holding PersistState
#define NVS_STATE_VERSION   1             // on-flash schema version
#define NVS_MAGIC           0x5A          // first-pass sentinel / blank-flash reject
#define NVS_SETTLE_MS       750           // defer commit until no change for this long
#define NVS_BACKSTOP_MS     60000         // periodic backstop commit interval
#define POT_IIR_ALPHA   0.10f
#define DEADBAND_LENGTH     1   // steps
#define DEADBAND_PLAY_MODE  0   // index — any change counts (range is only 0–7)
#define DEADBAND_STEP_DIV   0   // index — any change counts (range is only 0–12)
#define DEADBAND_PARAM_MODE 0   // index — any change counts (range is only 0–2)
#define DEADBAND_BASE_NOTE  1   // MIDI note
#define DEADBAND_NOTE_RANGE 1   // MIDI note
#define DEADBAND_VEL        1   // velocity
#define DEADBAND_DUR        1   // steps
#define DEADBAND_SLICE_CTR  1   // degrees
#define DEADBAND_SLICE_WID  1   // degrees
#define DEADBAND_SLICE_BRI  1   // brightness units
#define DEADBAND_MIDI_CH    0   // channel — any change counts
#define DEADBAND_PLAY_DIR   0   // direction — any change counts (range is 0–1)
#define BTN_DEBOUNCE_MS     20      // ms hold-off after edge
#define LENGTH_MIN          1
#define LENGTH_MAX         32
#define PLAY_MODE_MIN       0       // random
#define PLAY_MODE_MAX       7       // dimmest
#define STEP_DIV_MIN        0       // index → 1/32
#define STEP_DIV_MAX       12       // index → 4
#define PARAM_MODE_MIN      0       // parameterised
#define PARAM_MODE_MAX      2       // random_per_loop
#define BASE_NOTE_MIN      36       // C2 (MIDI note-name convention: MIDI 0 = C-1)
#define BASE_NOTE_MAX      83       // B5
#define NOTE_RANGE_MIN      0
#define NOTE_RANGE_MAX     24
#define VEL_MIN             0
#define VEL_MAX           127
#define DUR_MIN_STEPS       1       // steps
#define DUR_MAX_STEPS      64
#define SLICE_CENTRE_MIN    0       // degrees, compass bearing, 0 = North
#define SLICE_CENTRE_MAX  359
#define SLICE_WIDTH_MIN     1       // degrees
#define SLICE_WIDTH_MAX   359
#define SLICE_BRIGHT_MIN    0       // 0 = dimmest/most permissive
#define SLICE_BRIGHT_MAX  100
#define MIDI_CH_MIN         1
#define MIDI_CH_MAX        16
#define PLAY_DIR_MIN        0       // reverse (pot fully left)
#define PLAY_DIR_MAX        1       // forward (pot fully right)
#define MODE_STOPPED    0
#define MODE_MONO       1
#define MODE_POLY       2
#define DEFAULT_VEL_LO       80     // fixed velocity low
#define DEFAULT_VEL_HI      120     // fixed velocity high
#define DEFAULT_DUR_LO        1     // fixed duration low (steps)
#define DEFAULT_PARAM_MODE    0     // PARM (parameterised)
#define PAGE_1  1

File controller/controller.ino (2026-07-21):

// =============================================================================
//  Seedquencer — Instrument Controller Firmware
//  controller.ino
//
//  Pot mapping:
//    Pot 1: Length         Pot 2: Base note     Pot 3: Note range
//    Pot 4: Slice centre   Pot 5: Step divider  Pot 6: Slice width
//    Pot 7: Play mode      Pot 8: Slice bright  Pot 9: Duration Hi (1..len)
//
//  Fixed defaults (not pot-driven, transmitted in every payload):
//    Velocity Lo = 80   Velocity Hi = 120   Duration Lo = 1
//    Parameter mode = PARM (0)   MIDI channel = controller_id
//
//  SPDT 1 (PIN_SPDT1): Mute/Stop — tx_mode = 0 when HIGH (engaged).
//  SPDT 2 (PIN_SPDT2): Mono/Poly — tx_mode = 1 (mono) or 2 (poly).
//  Button (PIN_BTN_DIR): toggles play_direction on debounced release.
//
//  Payload: 26 bytes + COBS framing
//
//  Libraries required (install via Arduino Library Manager):
//    - Adafruit SSD1306       (OLED driver)
//    - Adafruit GFX Library   (graphics primitives, dependency of SSD1306)
//    - Adafruit BusIO         (I2C/SPI abstraction, dependency of SSD1306)
//
//  Note:
//    GPIO47 and the free use of GPIO6–11 are only valid on the ESP32-S3.
//    If using a different board you'll need to figure out what works on
//    your version.
//
// =============================================================================

#include <Wire.h>
#include <Adafruit_GFX.h>
#include <Adafruit_SSD1306.h>

#include "config.h"
#include "inputs.h"
#include "display.h"
#include "serial_tx.h"
#include "nvs_store.h"

// ---------------------------------------------------------------------------
//  Timing
// ---------------------------------------------------------------------------
static const uint32_t SCAN_INTERVAL_MS = 5;    // 200 Hz input scan
static const uint32_t OLED_INTERVAL_MS = 50;   // 20 Hz display refresh

static uint32_t lastScanMs = 0;
static uint32_t lastOledMs = 0;

// ---------------------------------------------------------------------------
//  Global state
// ---------------------------------------------------------------------------
ControllerState g_state;

// ---------------------------------------------------------------------------
//  OLED instance
// ---------------------------------------------------------------------------
Adafruit_SSD1306 g_display(OLED_WIDTH, OLED_HEIGHT, &Wire, OLED_RESET_PIN);

// ---------------------------------------------------------------------------
//  setup()
// ---------------------------------------------------------------------------
void setup() {
    Serial.begin(115200);
    Serial.println(F("BOOT v5"));

    Wire.begin(PIN_I2C_SDA, PIN_I2C_SCL);

    inputs_init();
    serial_tx_init();
    display_init(g_display);
    nvs_store_init();

    g_state.controller_id = CONTROLLER_ID;
    g_state.active_page   = PAGE_1;
    g_state.tx_mode       = MODE_MONO;

    // Attempt to restore persisted parameter state. On success, the loaded values 
    // are preserved and pickup is armed against live pot positions; on failure
    // (no/invalid record) fall back to seeding everything from live pots.
    if (nvs_store_load(g_state)) {
        // Loaded values + restored active_page are already in g_state.
        // Arm pickup without overwriting them.
        inputs_arm_pickup_from_stored(g_state);
        Serial.println(F("Restored state from NVS"));
    } else {
        // Fresh boot: seed all parameters from current pot positions
        // and mark everything picked-up.
        inputs_seed_from_pots(g_state);
        Serial.println(F("No valid NVS record; seeded from pots"));
    }

    // tx_mode is (re)computed from live SPDT positions on the first scan
}

// ---------------------------------------------------------------------------
//  loop()
// ---------------------------------------------------------------------------
void loop() {
    uint32_t now = millis();

    if (now - lastScanMs >= SCAN_INTERVAL_MS) {
        lastScanMs = now;
        inputs_scan(g_state);
        serial_tx_update(g_state);
        nvs_store_update(g_state);   // change-driven, debounced flash persistence
    }

    if (now - lastOledMs >= OLED_INTERVAL_MS) {
        lastOledMs = now;
        display_update(g_display, g_state);
    }
}

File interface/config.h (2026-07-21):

#pragma once
// =============================================================================
//  config.h — Pin assignments, timing, and protocol constants
// =============================================================================

// ---------------------------------------------------------------------------
//  Controller port pin assignments
//  Each pair is RX/TX on consecutive GPIO numbers.
// ---------------------------------------------------------------------------
#define NUM_CONTROLLERS     8

static const uint8_t CTRL_RX_PINS[NUM_CONTROLLERS] = {  2,  4,  6,  8, 10, 12, 14, 16 };
static const uint8_t CTRL_TX_PINS[NUM_CONTROLLERS] = {  3,  5,  7,  9, 11, 13, 15, 17 };

// ---------------------------------------------------------------------------
//  Uplink to Raspberry Pi (HW UART1)
// ---------------------------------------------------------------------------
#define UPLINK_TX_PIN       20      // GP20
#define UPLINK_RX_PIN       21      // GP21
#define UPLINK_BAUD         57600

// ---------------------------------------------------------------------------
//  Baud rates
// ---------------------------------------------------------------------------
#define CTRL_BAUD           57600   // Controller → Interface

// ---------------------------------------------------------------------------
//  Protocol — must match controller firmware
//
//  downstream payload (Controller → Interface):
//    [0]     Protocol version (5)
//    [1]     Controller ID (1–8)
//    [2]     Sequence number
//    [3–6]   Timestamp ms (uint32 LE)
//    [7]     Mode (0=stopped, 1=mono, 2=poly)
//    [8]     Length (1–32 steps)
//    [9]     Play mode (0–7 index)
//    [10]    Step divider (0–12 index)
//    [11]    Parameter mode (0–2 index)
//    [12]    Play direction (0=reverse, 1=forward)     <-- v5, new
//    [13]    Base note (0–127 MIDI)
//    [14]    Note range (0–127 MIDI)
//    [15]    Velocity Lo (0–127)
//    [16]    Velocity Hi (0–127)
//    [17]    Duration Lo (1–64 steps)
//    [18]    Duration Hi (1–64 steps)
//    [19–20] Slice centre (uint16 LE, 0–359°)
//    [21–22] Slice width  (uint16 LE, 1–360°)
//    [23]    Slice brightness (0–100)
//    [24]    MIDI channel (1–16)
//    [25]    CRC-8 (Dallas/Maxim, poly 0x31) over bytes 0–24
//
// ---------------------------------------------------------------------------
#define PROTO_VERSION       5
#define CTRL_PAYLOAD_LEN    26      // decoded bytes including CRC

// Mode constants
#define MODE_STOPPED        0
#define MODE_MONO           1
#define MODE_POLY           2

// Play direction constants (v5)
#define DIR_REVERSE         0
#define DIR_FORWARD         1

// Upstream packet types
#define PKT_TYPE_FULL       0x01    // Full 8-controller snapshot
#define PKT_TYPE_DELTA      0x02    // Single changed controller record

// ---------------------------------------------------------------------------
//  Timeout policy
// ---------------------------------------------------------------------------
#define STALE_MS            500
#define OFFLINE_MS          2000

// ---------------------------------------------------------------------------
//  Upstream forwarding
// ---------------------------------------------------------------------------
#define SNAPSHOT_INTERVAL_MS    400     // Full snapshot heartbeat

// ---------------------------------------------------------------------------
//  Upstream TX activity LED
//  Onboard LED toggles every TX_LED_PACKET_INTERVAL packets sent (delta or
//  full), as a simple "uplink is alive" indicator independent of the boot
//  blink pattern. Non-blocking — toggled in upstream_tx.cpp, no delay().
// ---------------------------------------------------------------------------
#define TX_LED_PACKET_INTERVAL   2     // Toggle LED every N packets sent

// ---------------------------------------------------------------------------
//  Upstream TX deadbands
//  Minimum change in a field value before flagging a delta for transmission.
// ---------------------------------------------------------------------------
#define TX_DEADBAND_NOTE          1    // base_note, note_range
#define TX_DEADBAND_VEL           1    // vel_lo, vel_hi
#define TX_DEADBAND_DUR           1    // dur_lo, dur_hi (steps)
#define TX_DEADBAND_SLICE_CENTRE  1    // degrees
#define TX_DEADBAND_SLICE_WIDTH   1    // degrees
#define TX_DEADBAND_SLICE_BRIGHT  1    // 0–100 units

// ---------------------------------------------------------------------------
//  RX buffer
// ---------------------------------------------------------------------------
#define MAX_FRAME_BYTES     32      // max COBS-encoded frame size

// ---------------------------------------------------------------------------
//  Onboard LED and VBUS sense
// ---------------------------------------------------------------------------
#define LED_PIN             25      // GP25 — onboard LED
#define VBUS_SENSE_PIN      24      // GP24 — high when powered via USB VBUS
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

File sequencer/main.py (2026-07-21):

import sys
import os
import queue
import logging
import argparse

logging.basicConfig(
    level=logging.INFO,
    format="%(asctime)s  %(threadName)-18s  %(levelname)-8s  %(message)s",
)
logger = logging.getLogger(__name__)

# Ensure the project root is on sys.path so all packages resolve correctly
sys.path.insert(0, os.path.dirname(os.path.abspath(__file__)))


def main():
    parser = argparse.ArgumentParser(
        description="starseq — star-position-driven MIDI step sequencer",
    )
    parser.add_argument(
        "--no-gpio",
        action="store_true",
        help="Disable GPIO input handler; use keyboard shortcuts instead",
    )
    parser.add_argument(
        "--no-serial",
        action="store_true",
        help="Disable serial RX; all tracks start in mono mode with built-in defaults",
    )
    parser.add_argument(
        "--resolution",
        metavar="WxH",
        help="Force a specific window size for testing, e.g. 800x480 or 1920x1080",
    )
    parser.add_argument(
        "--rotation",
        type=int,
        choices=[0, 90, 180, 270],
        default=0,
        help="Display rotation in degrees clockwise (90/270 use stacked portrait layout)",
    )
    parser.add_argument(
        "--midi-channels",
        default="1 2 3 4 5 6 7 8",
        metavar="'1 2 3 4 5 6 7 8'",
        help="MIDI output channel per track (space-separated, 8 values from 1–16)",
    )
    args = parser.parse_args()

    resolution = None
    if args.resolution:
        try:
            w_str, h_str = args.resolution.lower().split("x")
            resolution = (int(w_str), int(h_str))
        except (ValueError, AttributeError):
            print("Error: --resolution must be in WxH format, e.g. 1280x720")
            sys.exit(1)

    try:
        launch_channels = [int(x) for x in args.midi_channels.split()]
        if len(launch_channels) != 8 or not all(1 <= c <= 16 for c in launch_channels):
            raise ValueError
    except ValueError:
        print("Error: --midi-channels must be 8 values from 1–16, e.g. '1 2 3 4 5 6 7 8'")
        sys.exit(1)

    import config
    from transport.state import TransportState, SCALE_NAMES
    from tracks.state import TrackStateStore
    from sky.time_sim import SimulatedClock
    from sky.engine import SkyEngine
    from sky.constellations import load_constellation_lines
    from tracks.builder import SequenceBuilder
    from sequencer.midi_output import MIDIOutput
    from sequencer.engine import SequencerEngine
    from sequencer.midi_clock_input import MidiClockInput
    from serial_rx.receiver import SerialRXThread
    from display.renderer import DisplayRenderer
    from input.handler import InputHandler, InputEvent
    from menu_state import MenuState
    from gps.receiver import GpsReceiver

    base_dir = os.path.dirname(os.path.abspath(__file__))
    catalogue_path = os.path.join(base_dir, config.CATALOGUE_PATH)
    ephemeris_path = os.path.join(base_dir, config.EPHEMERIS_PATH)
    constellation_lines_path = os.path.join(base_dir, config.CONSTELLATION_LINES_PATH)
    try:
        constellation_lines = load_constellation_lines(constellation_lines_path)
        logger.info("Loaded constellation lines for %d constellations", len(constellation_lines))
    except OSError as exc:
        logger.warning("Could not load constellation lines (%s); overlay will be empty", exc)
        constellation_lines = {}

    # --- State ---
    transport = TransportState()
    transport.launch_channels = launch_channels
    track_store = TrackStateStore(8)
    for i, ch in enumerate(launch_channels):
        track_store[i].midi_channel = ch
    sim_clock = SimulatedClock()
    menu_state = MenuState()

    # --- Queues ---
    sky_queue = queue.Queue(maxsize=1)  # SkyEngine → SequenceBuilder
    flash_events = queue.Queue(maxsize=200)  # SequencerEngine → DisplayRenderer
    input_queue = queue.Queue(maxsize=50)  # InputHandler → main loop
    ext_clock_queue = queue.Queue(maxsize=10)  # external MIDI clock → SequencerEngine

    # --- MIDI ---
    midi_out = MIDIOutput()
    available = MIDIOutput.get_output_names()
    if available:
        transport.midi_device = available[0]
        midi_out.open(transport.midi_device)
    else:
        logger.warning("No MIDI output devices found; MIDI output disabled")
    menu_state.midi_devices = available

    # --- Apply defaults when serial is disabled ---
    if args.no_serial:
        _apply_demo_defaults(track_store)
        logger.info("Serial disabled — all tracks set to mono with built-in defaults")
    if args.no_gpio:
        logger.info(
            "GPIO disabled — keyboard shortcuts active "
            "(P=play/stop  R=reset clock  Space=menu  arrows=navigate/adjust)"
        )

    # --- Create threads ---
    input_handler = InputHandler(input_queue)
    serial_rx = SerialRXThread(config.SERIAL_PORT, track_store, config.SERIAL_BAUD, transport)
    sky_engine = SkyEngine(sim_clock, sky_queue, catalogue_path, ephemeris_path, transport=transport)
    seq_builder = SequenceBuilder(track_store, transport, sky_queue)
    input_callback = lambda ev: _handle_input(
        ev, transport, sim_clock, midi_out, track_store, menu_state
    )
    display = DisplayRenderer(
        transport,
        track_store,
        sky_engine,
        flash_events,
        menu_state=menu_state,
        input_queue=input_queue,
        resolution=resolution,
        sim_clock=sim_clock,
        input_callback=input_callback,
        rotation=args.rotation,
        constellation_lines=constellation_lines,
    )
    seq_engine = SequencerEngine(track_store, transport, midi_out, ext_clock_queue)
    seq_engine.flash_events = flash_events
    midi_clock_in = MidiClockInput(transport, ext_clock_queue)
    gps_receiver = GpsReceiver(transport)

    # --- Start background threads ---
    logger.info("Starting starseq...")
    started = []

    if not args.no_gpio:
        input_handler.start()
        started.append(input_handler)

    if not args.no_serial:
        serial_rx.start()
        started.append(serial_rx)

    for t in (sky_engine, seq_builder, seq_engine, midi_clock_in, gps_receiver):
        t.start()
        started.append(t)

    logger.info("Running. Press Ctrl-C to quit.")

    # pygame must run on the main thread on Linux/RPi — call run() directly
    try:
        display.run()
    except KeyboardInterrupt:
        logger.info("Keyboard interrupt — shutting down")

    _shutdown(started, midi_out)
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
